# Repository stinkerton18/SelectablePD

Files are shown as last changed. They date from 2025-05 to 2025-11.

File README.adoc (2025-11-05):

## Purpose
While USB-PD->DC cables exist, these are preset to a specific voltage. Using the same USB-PD with different devices requiring different voltages means unplugging and plugging in a different cable for each device. There has to be a better solution, and thanks to Adafruit, we can make it!
This design uses 4 LED lit push button switches, and a 0.91 inch OLED screen, to choose from 5v (default), 9v, 12v, and 20v. When first turned on, 5v is chosen by default.



## Usage
The unit requires the following power inputs:
[cols=2*,options=]
|===
|5v to Arduino
| Ensure the Arduino receieves a consistent power output and preserve all available current through USB-PD is available for any devices you have connected.
| USB-PD
| The main power input. Please ensure your USB-PD power supply supports all of the voltages you plan to use.
|===
Pressing a specific voltage pushbutton results in that switch lighting up and the OLED screen displaying the currently operating voltage. If the selected voltage cannot be set, either due to a communications error or the USB-PD power source not supporting that voltage, an error will be displayed and the previously working voltage left enabled.

## Status
Tested, validated with a volt meter, ready for prime time!

## Components
[cols="^,<,<,^",options=header]
|===
| Quantity
| Name
| Purpose
| Link
| 1
| Adafruit USB Type C Power Delivery (HUSB238)
| Does USB-PD heavy lifting and supports I2C control for "on the fly" voltage changes.
| https://www.adafruit.com/product/5807
| 1
| Adafruit Monochrome 0.91 inch Display (OLED)
| Provides a feedback mechanism to the user to confirm if the chosen voltage was changed successfully or if the USB-PD power source does not support that voltage.
| https://www.adafruit.com/product/4440
| 4
| Adafruit 16mm Illuminated Push Button Momentary
| Used to choose which voltage you want.
| https://www.adafruit.com/product/1440
| 1
| Arduino Micro 328 (5V 16Mhz version)
| The control brains. Contains the code to control the USB-PD board and OLED screen.
| https://www.sparkfun.com/arduino-pro-mini-328-5v-16mhz.html
| 4
| 10k Ohm Resistors
| Pulldown resistor for each switch.
| Favorite component source
| 1
| 330 (or 470) Ohm Resistor
| Current limiting resistor for LEDs for indicating the currently enabled voltage.
| Favorite component source
| 1
| DIY OEM Type C Female Socket
| Provides a dedicated 5v power for control Arduino
| https://www.amazon.com/dp/B0D5B82V6K
|===

## Wiring Diagram
I've include both a checklist-type wiring diagram, and a Fritzing diagram in an effort to reach the widest audience of other makers.

Below is the table of Arduino Pins to component pins/pads, if there is an inline resistor, and a handy extra space to mark off when you've completed that connection.
[cols="^,^,^,^",options="header"]
|===
| Arduino Micro 328 Pin
| Inline Resistor Value
| Component Pin/Pad
| Done?
| Ground
| 330 Ohm (or 470 Ohm)
| Cathode (negative) of each LED. All LEDs can be tied together and linked to one resistor
|
| Ground
| 10K Ohm
| Pin 1 of "5v" Switch
|
| Ground
| 10K Ohm
| Pin 1 of "9v" Switch
|
| Ground
| 10K Ohm
| Pin 1 of "12v" Switch
|
| Ground
| 10K Ohm
| Pin 1 of "20v" Switch
|
| 5v (Vcc on some Arduino models)
| 
| Pin 2 of each Switch, VIN on OLED
|
| 2 (Digital Pin)
| 
| Pin 1 of "20v" Switch
|
| 3 (Digital Pin)
| 
| Pin 1 of "12v" Switch
|
| 4 (Digital Pin)
| 
| Pin 1 of "9v" Switch
|
| 5 (Digital Pin)
| 
| Pin 1 of "5v" Switch
|
| 6 (Digital Pin)
| 
| Anode (positive) of "20v" indicator LED
|
| 7 (Digital Pin)
| 
| Anode (positive) of "12v" indicator LED
|
| 8 (Digital Pin)
| 
| Anode (positive) of "9v" indicator LED
|
| 9 (Digital Pin)
| 
| Anode (positive) of "5v" indicator LED
|
| A4 (Hardware SDA pin)
| 
| SDA pins on OLED and HUSB238
|
| A5 (Hardware SDA pin)
| 
| SCL pins on OLED and HUSB238
| 
|===

For visually oriented folks, here is a Fritzing wiring diagram with an Arduino Micro 328:
The power/barrel connector is the 5V input (separate from HUB238).
The pigtail breakout is the 5V/9V/12V/20V output from the HUB238.

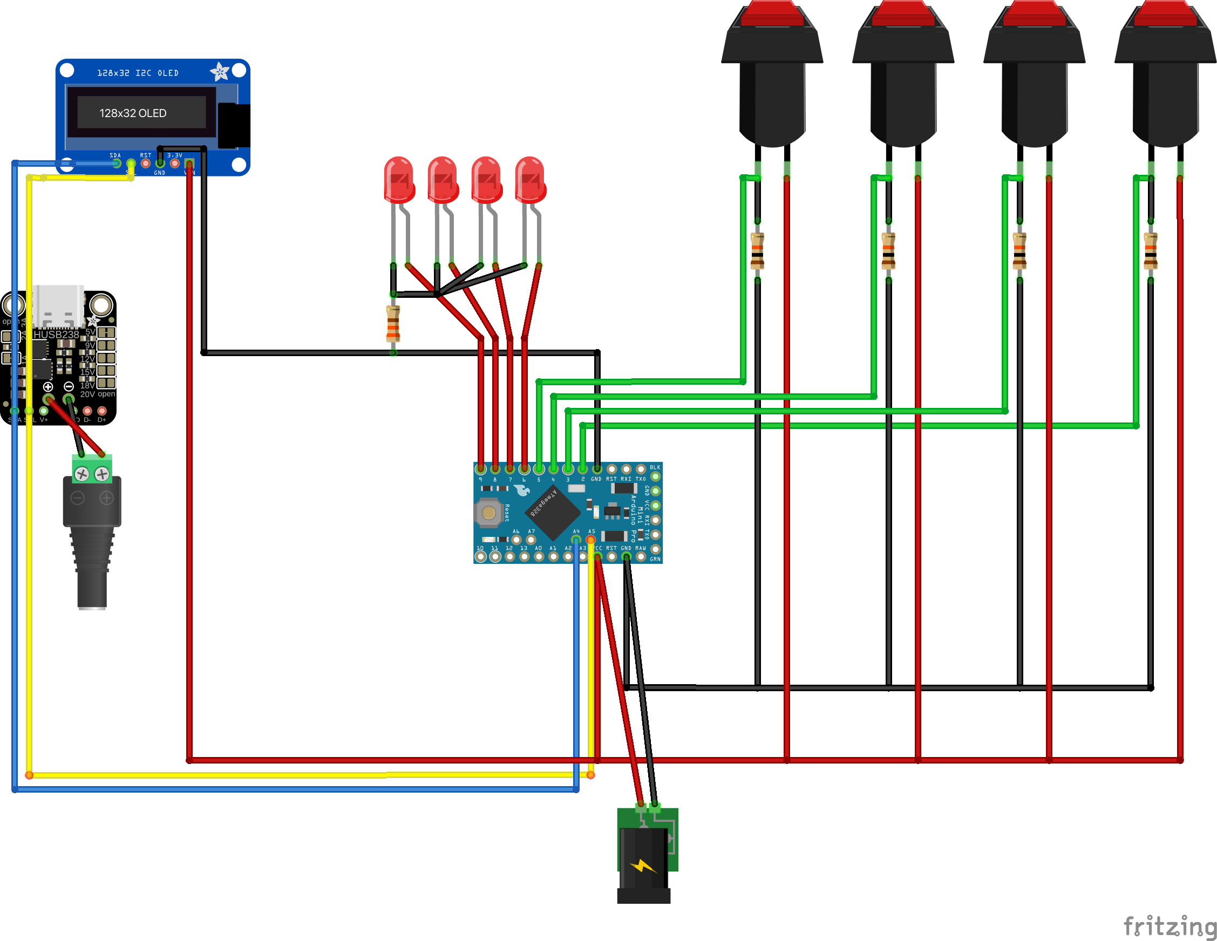
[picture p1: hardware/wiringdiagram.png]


It is possible to tie common lines together. Here's the assembly I did  on mine in the GIF above:

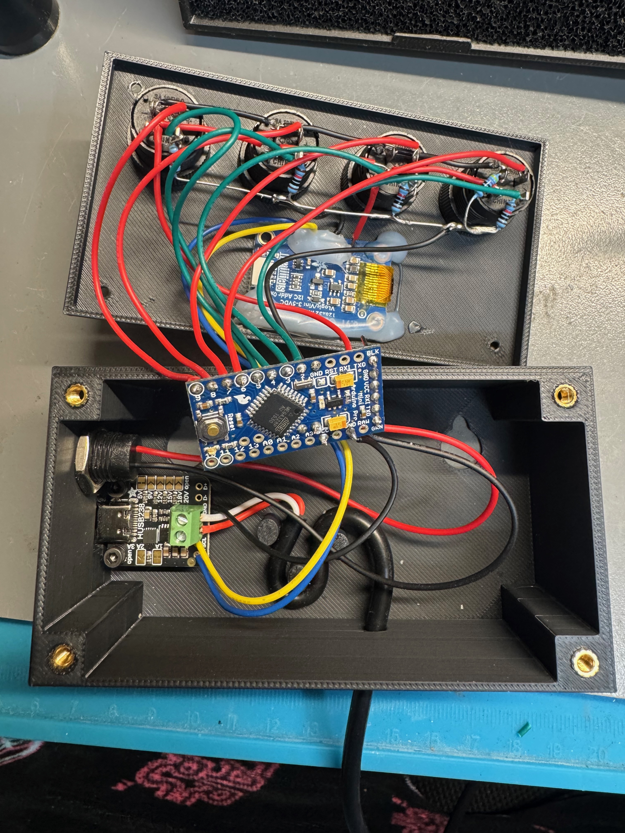
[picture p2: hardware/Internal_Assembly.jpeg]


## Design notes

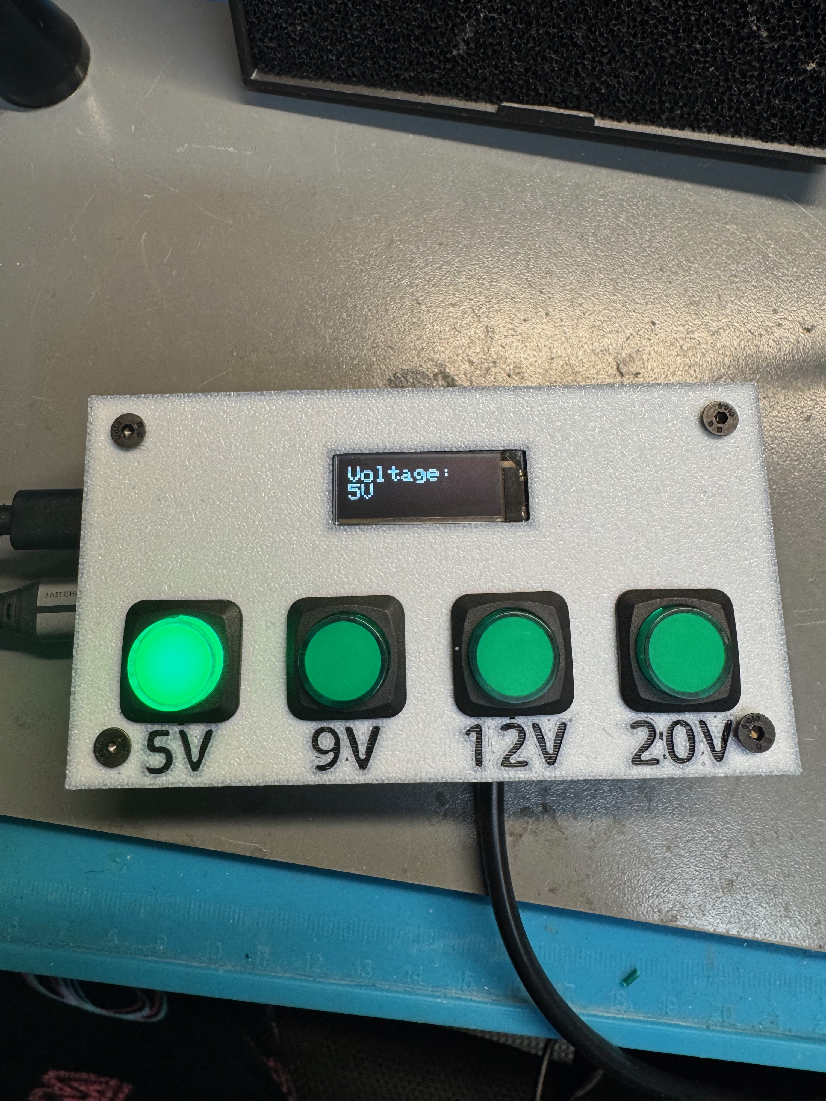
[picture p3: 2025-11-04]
hardware/5v.jpeg

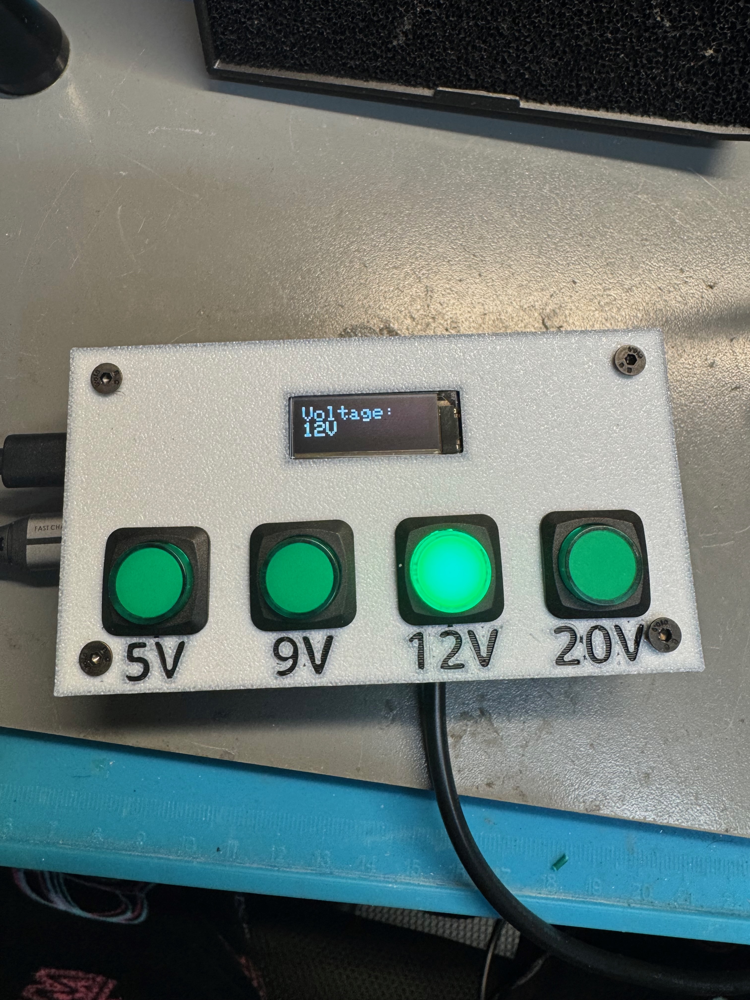
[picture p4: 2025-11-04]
hardware/12v.jpeg

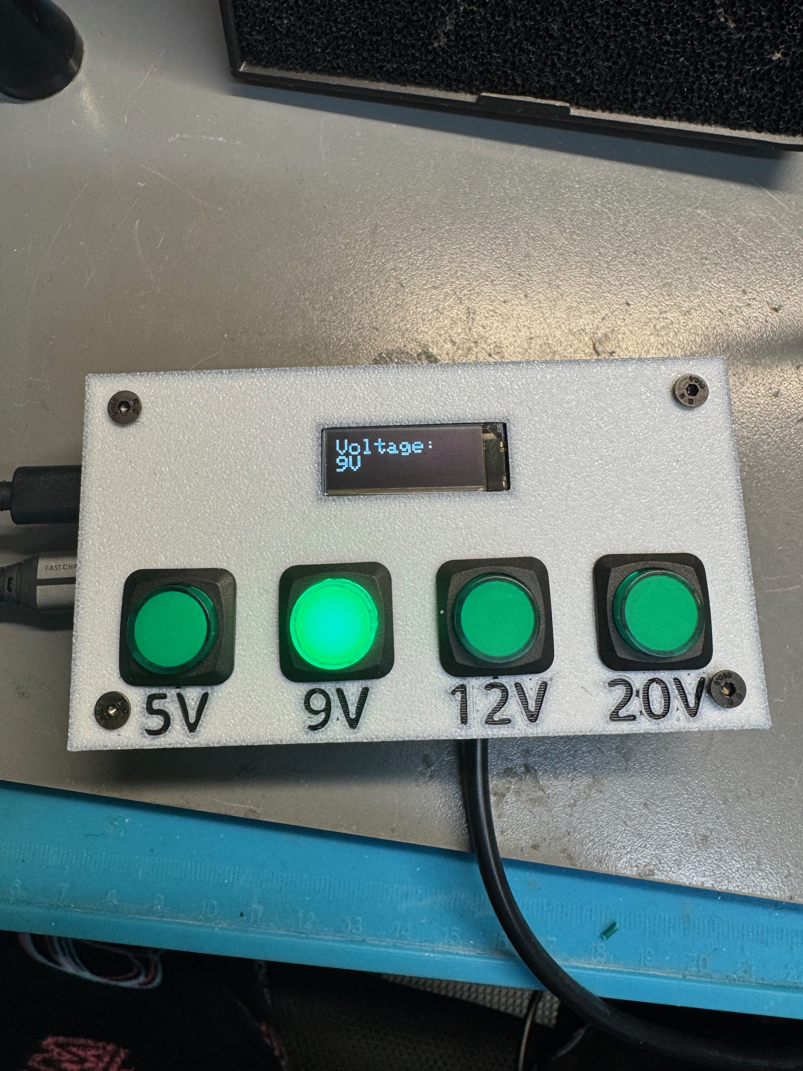
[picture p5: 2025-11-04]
hardware/9v.jpeg

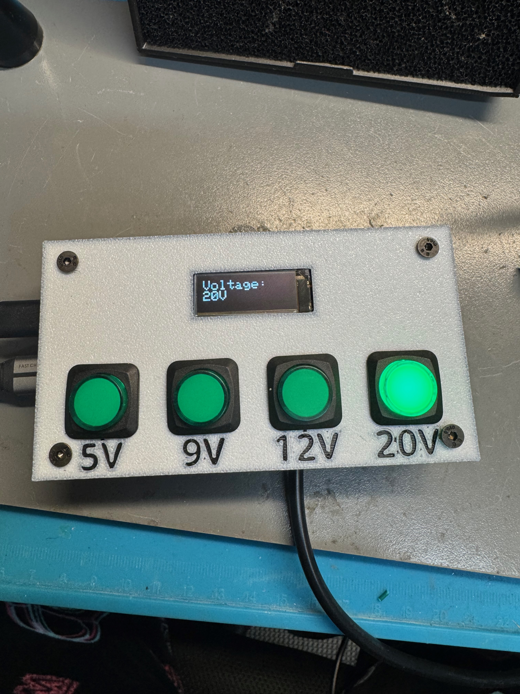
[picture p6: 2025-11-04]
hardware/20v.jpeg

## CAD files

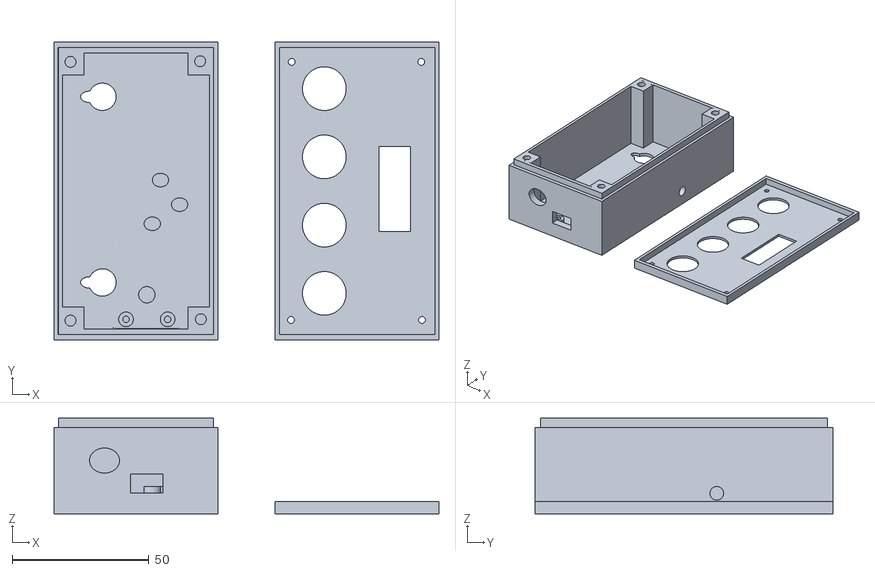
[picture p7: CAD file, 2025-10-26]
hardware/SelectablePD Case - Full.stl
141.0 x 109.0 x 35.0

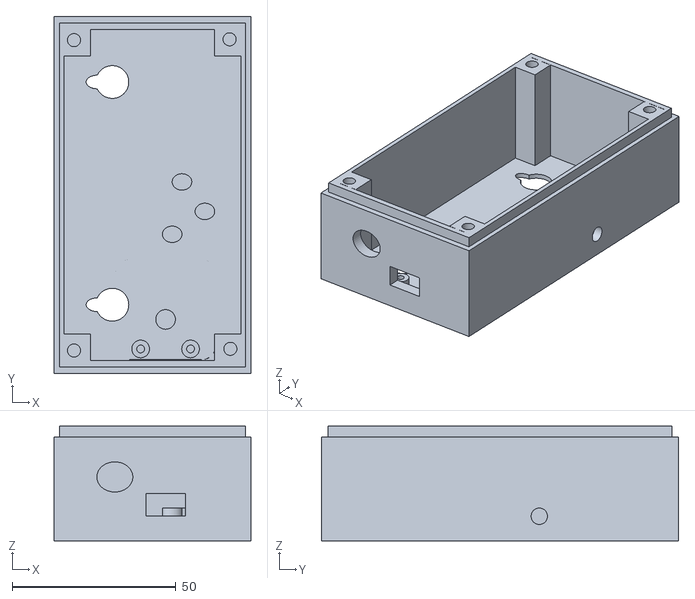
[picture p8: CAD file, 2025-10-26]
hardware/Case Bottom.stl
60.0 x 109.0 x 35.0

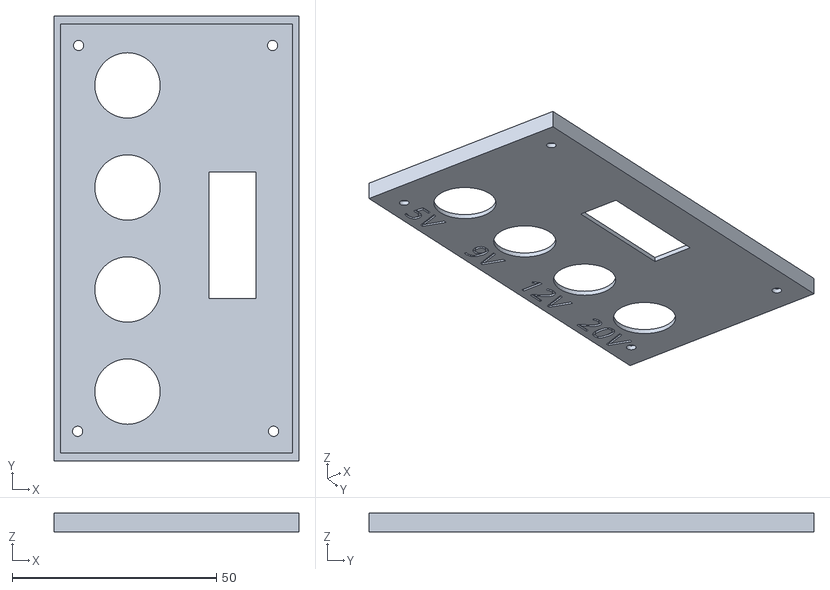
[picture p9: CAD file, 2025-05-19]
hardware/Case Top.stl
60.0 x 109.0 x 4.55

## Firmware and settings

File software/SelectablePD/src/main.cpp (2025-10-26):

/**************************************************************************
Code for the USB-PD to 5v/9v/12v/20v power adapter
Credit to Adafruit for both their HUSB238 breakout board and 0.91" OLED screen
HUSB238 - https://www.adafruit.com/product/5807
OLED Screen - https://www.adafruit.com/product/4440
 **************************************************************************/
#include <Arduino.h>
#include <SPI.h>
#include <Wire.h>
#include <Adafruit_GFX.h>
#include <Adafruit_SSD1306.h>
#include "Adafruit_HUSB238.h"

#define SCREEN_WIDTH 128 // OLED display width, in pixels
#define SCREEN_HEIGHT 32 // OLED display height, in pixels

// Declaration for an SSD1306 display connected to I2C (SDA, SCL pins)
// The pins for I2C are defined by the Wire-library. 
// On an arduino UNO:       A4(SDA), A5(SCL)
// On an arduino MEGA 2560: 20(SDA), 21(SCL)
// On an arduino LEONARDO:   2(SDA),  3(SCL), ...
#define OLED_RESET     -1 // Reset pin # (or -1 if sharing Arduino reset pin)
#define SCREEN_ADDRESS 0x3C // Per the datasheet 0x3C for 128x32
Adafruit_SSD1306 display(SCREEN_WIDTH, SCREEN_HEIGHT, &Wire, OLED_RESET);

// Define the USB PD adapter:
Adafruit_HUSB238 usbpd;

// These values are used to check if a button was pressed
int Button5v = 0;
int Button9v = 0;
int Button12v = 0;
int Button20v = 0;
// This is used simply to keep a timeout for the screen and blank it to extend the life of the OLEDs
int Timeout = 0;
// Defining the buttons to pins on an Uno/Nano ATmega328P. Adjust to match your board/wiring
const int ButtonPin5v = 5;
const int ButtonPin9v = 4;
const int ButtonPin12v = 3;
const int ButtonPin20v = 2;
// Define the LED/indicators for the currently enabled voltage. Adjust to match your board/wiring
const int LED5v = 9;
const int LED9v = 8;
const int LED12v = 7;
const int LED20v = 6;

// A variable to help deter/avoid button bouncing
bool buttonPressed = false;

/*************************************************************** 
This function is for updating the OLED screen with a success (S)
and what voltage to display or if a failure (F) occurred.
***************************************************************/
void updateScreen(char result, String voltage) {
  // Ensure the display is cleared before updating
  display.clearDisplay();
  switch(result) {
  case 'S':
    // Display the new voltage
    Serial.println("Updating display with new voltage");
    display.clearDisplay();
    display.setTextSize(2); // Draw 2X-scale text
    display.setTextColor(SSD1306_WHITE);
    display.setCursor(0, 0);
    display.println("Voltage:  " + voltage);
    display.display();
    break;
  case 'F':
    // Display an error message
    Serial.println("Updating display with error message");
    display.clearDisplay();
    display.setTextSize(2); // Draw 2X-scale text
    display.setTextColor(SSD1306_WHITE);
    display.setCursor(0, 0);
    display.println("Unsupported");
    display.display();
    break;
  }
}

/*************************************************************** 
This function is for updating the USB-PD board to the requested voltage
***************************************************************/
void setvoltage (int voltage) {
  switch(voltage) {
    case 5:
      usbpd.selectPD(PD_SRC_5V);
      Serial.println("USB-PD Requested 5V");
      usbpd.requestPD();
      // Add a small delay to allow the PD request to process
      //delayMicroseconds(500);
      break;
    case 9:
      usbpd.selectPD(PD_SRC_9V);
      Serial.println("USB-PD Requested 9V");
      usbpd.requestPD();
      // Add a small delay to allow the PD request to process
      //delayMicroseconds(500);
      break;
    case 12:
      usbpd.selectPD(PD_SRC_12V);
      Serial.println("USB-PD Requested 12V");
      usbpd.requestPD();
      // Add a small delay to allow the PD request to process
      //delayMicroseconds(500);
      break;
    case 20:
      usbpd.selectPD(PD_SRC_20V);
      Serial.println("USB-PD Requested 20V");
      usbpd.requestPD();
      // Add a small delay to allow the PD request to process
      //delayMicroseconds(500);
      break;
    default:
      Serial.println("Unsupported voltage selection");
      break;
  }
}

/***************************************************************
 * This function checks the voltage requested by the PD board
 * and updates the screen accordingly
 ***************************************************************/
void checkvoltage () {
  HUSB238_PDSelection srcVoltage = usbpd.getSelectedPD();
  Serial.println("USB-PD received " + srcVoltage);
  switch (srcVoltage)
  {
    case PD_SRC_5V:
      updateScreen('S', "5V");
      Timeout=0;
      break;
    case PD_SRC_9V:
      updateScreen('S', "9V");
      Timeout=0;
      break;
    case PD_SRC_12V:
      updateScreen('S', "12V");
      Timeout=0;
      break;
    case PD_SRC_20V:
      updateScreen('S', "20V");
      Timeout=0;
      break;
    default:
      updateScreen('F',"0V");
      Serial.println("Voltage request failed");
      Timeout=0;
      break;
  }
}

void setup()
{
  pinMode(ButtonPin5v, INPUT);    //  5v button
  pinMode(ButtonPin9v, INPUT);    //  9v button
  pinMode(ButtonPin12v, INPUT);    // 12v button
  pinMode(ButtonPin20v, INPUT);    // 20v button
  pinMode(LED5v, OUTPUT);  //  5v LED/indicator
  pinMode(LED9v, OUTPUT);  //  9v LED/indicator
  pinMode(LED12v, OUTPUT);  // 12v LED/indicator
  pinMode(LED20v, OUTPUT);   // 20v LED/indicator

  // Start serial console
//  Serial.begin(115200);
  Serial.begin(9600);
  while (!Serial) delay(10);
  Serial.println("Adafruit HUSB238 based selectable PD power supply starting");

  // Initialize the HUSB238
  if (usbpd.begin(HUSB238_I2CADDR_DEFAULT, &Wire)) {
    Serial.println("HUSB238 USB-PD initialized successfully.");
  } else {
    Serial.println("Couldn't find HUSB238 USB-PD, check your wiring?");
    for(;;); // Don't proceed, loop forever
  }

  // Initialize the OLED display
  if(display.begin(SSD1306_SWITCHCAPVCC, SCREEN_ADDRESS)) {
    Serial.println("SSD1306 OLED Screen initialized successfully.");
  } else {
    Serial.println("Couldn't find SSD1306 OLED Screen, check your wiring?");
    for(;;); // Don't proceed, loop forever
  }

  // On start, we set the voltage to 5v and set the appropriate indicator
  updateScreen('S', "5V");
  setvoltage(5);
  digitalWrite(LED5v, HIGH);
  Serial.println("Initialization complete");
}

void loop()
{
  // Read the state of the 5v pushbutton
  Button5v = digitalRead(ButtonPin5v);
  // Read the state of the 9v pushbutton  
  Button9v = digitalRead(ButtonPin9v);
  // Read the state of the 12v pushbutton
  Button12v = digitalRead(ButtonPin12v);
  // Read the state of the 20v pushbutton
  Button20v = digitalRead(ButtonPin20v);

  if (buttonPressed) {
    // If a button was already pressed, wait until all are released
    if (Button5v == LOW && Button9v == LOW && Button12v == LOW && Button20v == LOW) {
      buttonPressed = false; // Reset the flag when all buttons are released
    } else {
      return; // Exit the loop early to avoid multiple triggers
    }
  } else {
    // If no button was pressed, check if any button is currently pressed
    if (Button5v == HIGH || Button9v == HIGH || Button12v == HIGH || Button20v == HIGH) {
      buttonPressed = true; // Set the flag to indicate a button press
    }
  }
  
  // Check which button is pressed
  if (Button5v == HIGH) {
    // Turn on the 5V LED and the others off
    digitalWrite(LED5v, HIGH);
    digitalWrite(LED9v, LOW);
    digitalWrite(LED12v, LOW);
    digitalWrite(LED20v, LOW);
    Serial.println("5V LED lit, others turned off");
    // Set the USB-PD board to 5V
    setvoltage(5);
    // Check if it was successful
    checkvoltage();
  }
  
  if (Button9v == HIGH) {
    // Turn LED on
    digitalWrite(LED9v, HIGH);
    digitalWrite(LED5v, LOW);
    digitalWrite(LED12v, LOW);
    digitalWrite(LED20v, LOW);
    Serial.println("9V LED lit, others turned off");
    // Set the USB-PD board to 9V
    setvoltage(9);
    // Check if it was successful
    checkvoltage();
  }
  
  if (Button12v == HIGH) {
    // Turn LED on
    digitalWrite(LED12v, HIGH);
    digitalWrite(LED5v, LOW);
    digitalWrite(LED9v, LOW);
    digitalWrite(LED20v, LOW);
    Serial.println("12V LED lit, others turned off");
    // Set the USB-PD board to 12V
    setvoltage(12);
    // Check if it was successful
    checkvoltage();
  }
  
  if (Button20v == HIGH) {
    // Turn LED on
    digitalWrite(LED12v, LOW);
    digitalWrite(LED5v, LOW);
    digitalWrite(LED9v, LOW);
    digitalWrite(LED20v, HIGH);
    Serial.println("20V LED lit, others turned off");
    // Set the USB-PD board to 20V
    setvoltage(20);
    // Check if it was successful
    checkvoltage();
  }
  
  if (Timeout <= 3000) {
    Timeout++;
  } else {
    // We clear the display to help extend the life of the OLED screen
    display.clearDisplay();
  }
}

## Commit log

2025-01-31 Arduino Coe Upload
    Arduino code upload along with folder structure for simpler cloning and reproducing
2025-01-31 Uploading Diagrams
    Fritzing source and PNG diagrams
    [SelectablePD.fzz]
2025-05-19 Printable Case
    Adding the 3D printable case in full, and separate top/bottom files.
    [Case Bottom.stl, Case Top.stl, SelectablePD Case - Full.stl]
2025-05-19 Update README.adoc
    Updated ToDo/Done lists, added an additional component for ease of Arduino power source
2025-05-19 Case Bottom Adjustments
    Correcting for height reduction causing unexpected dimension shifts of port/cord openings, screw holes, and mounting tabs.
    [Case Bottom.stl]
2025-05-20 Add files via upload
    Further tweaks to case bottom to accommodate incorrect measurements of USB-C to 2-wire pass through plug
    [Case Bottom.stl]
2025-05-26 Update wiringdiagram.png
    Removed dangerous/incorrect ground/voltage lines from USB-PD module.
2025-05-26 Shift to Arduino Micro
    Shifted BOM, code, and wiring diagrams to use an Arduino Micro 328. It's more sensible and fits within the project's included case STL easily.
    [SelectablePD-Arduino-Micro.fzz, SelectablePD.fzz]
2025-05-26 Updated diagram
    Adjusted diagram to show 5V input to Arduino and OLED screen, along with output from HUB238 module.
    [SelectablePD-Arduino-Micro.fzz]
2025-10-25 PlatformIO Migration
    Migraded code to PlatformIO for better library versioning and linking.
    Fixed an issue with with improper voltage checking
    Fixed a bug with improper display clearing after a power change failure
    [main.cpp]
2025-10-26 Functionality validation
    Fixed voltage set/check code
    Broke out voltage set/check into separate functions
    Added code to avoid button "bouncing"
    Validated, via voltmeter, output is now properly set
    [main.cpp]
2025-10-26 Case design fix
    Corrected issue with USB-PD port opening being too small for better quality cable connectors.
    [Case Bottom.stl, SelectablePD Case - Full.stl]
2025-11-04 Device photos
    Adding photos of the assembled device and each setting.
2025-11-05 Update README with images for functionality and assembly
    Added images to enhance the documentation and clarify the assembly process.
